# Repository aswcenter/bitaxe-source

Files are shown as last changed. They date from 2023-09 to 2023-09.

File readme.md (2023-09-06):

```
Closed Source is Antithetical to Bitcoin
```
# Presenting: The bitaxe
bitaxe is the first fully open source hardware Bitcoin ASIC miner.
bitaxeMax assembled

## Goals
- **Standalone**: can mine directly to your pool over WiFi. No External computer needed.
- **Embedded**: low cost, low maintenance, high availability, high reliability, low power.
- **ASIC**: based on the very efficient BM1397 from Bitmain.
- **Versatile**: solo/pool mining, autotune power/heat/efficiency.
- **Open Source**: All design files are provided.

## Features
- **ESP32-S3-WROOM-1** wifi microcontroller on board
- **TI TPS40305** buck regulator steps down the 5V input to power the BM1397
- **Maxim DS4432U+** current DAC digitally adjusts the BM1397 core voltage from 0.04V to 2.4V
- **TI INA260** power meter measures the input voltage and current of the miner
- **Microchip EMC2101** measures the BM1397 internal diode temperature. Also PWM controls the fan and monitors tach output.
- Two **sweet** RGB status LEDs
- 0.91" **SSD1306 OLED** I2C Display Module 

## BM1397
BM1397 pic

- The BM1397 is a undocumented SHA256 mining ASIC from Bitmain. It's mostly used in the Antminer S17 and T17
- Bitmain claims the BM1397 has 0.03J/GH efficiency
- The BM1397 is available (new) for around $20 each and (used) for around $6 ea in small quantities.
- Choose your BM1397 version: [Guide here](https://d-central.tech/bm1397-ad-ag-ah-ai-antminer-17-series-chip-replacement-guide/)
- The BM1397 has the same footprint as the BM1387, but a very different pinout.
    - It also has two "Modes" that change some of the signal pins around to make chaining easy
- The BM1397 is driven by an undocumented protocol over UART. Baudrate is 115200bps by default but can go up to 6Mbps in order to provide mining jobs quickly enough to the ASIC daisy-chain.

## Current Status
- v2.2 hardware has been built and tested -- it works!
- Using cgminer on a separate computer, the bitaxe can mine in excess of 400 GH/s
- ESP32 miner firmware is still underdevelopment.
    - Recently we have confirmed this is working! But it is not yet optimized. Check out [ESP-Miner](https://github.com/skot/esp-miner/tree/nonce_checking) for the latest. 
- This is an _advanced_ build! It's also still early days, so prolly not the best thing if you're just looking for a bitcoin miner to run.

## Hardware
- [BM1397 from random AliExpress seller](https://www.aliexpress.com/item/3256802274958527.html). I got the "AG" variant. Not really sure what the difference is.
- [40x40mm heatsink and 5V fan](https://www.aliexpress.com/item/2251832861666365.html) from a random AliExpress seller. At least half of these arrived broken in some way. But they are cheap and the working ones do keep the BM1387's nice and cool when used with some thermal compound.
    - Swap this fan with the [Noctua NF-A4x10](https://noctua.at/en/products/fan/nf-a4x10-pwm) 5V 4-Pin fan for a much more pleasant experience.
- The BM1397 serial port is 1.8V. These pins are broken out, but the main idea is to communicate with the BM1397 from the ESP32
- Level shifters to interface the 1.8V BM1397 with the 3.3V ESP32. These pins are also broken out.
- [KiCad 7](https://www.kicad.org) design files
- All of the parts on the board are listed in the KiCad BOM

## Software
- [ESP-Miner](https://github.com/skot/ESP-Miner) firmware in progress.
    - check out the `i2c_test` branch for a basic firmware to init all hardware (besides BM1397)
    - check out the `nonce_checking` branch for the latest developments in the ESP32 miner

### Testing
One of the best ways currently to test a new bitaxe is with a usbserial adapter and cgminer running on a separate computer.
- You need a basic firmware running on the ESP32 that will power up the ASIC. [ESP-Miner i2c_test](https://github.com/skot/esp-miner/tree/i2c_test) is good for this.
- You need a **1.8V** ftdi usbserial adapter. there are several on Amazon based on the FT232RL and one called "jim.sh" built on the FT230X
    - Connect the usbserial adapter to the 1.8V serial debug header on the bitaxe. It's the one below the heatsink next to the fan connector.
        - Make sure to connect the usbserial adapter `RTS` line to the bitaxe `RST` pin. Yes, that spelling is correct.
- Download and build the [cgminer-bitaxe](https://github.com/skot/cgminer-bitaxe) fork. 
    - This fork has a modified version of the GekkoScience CompacF driver to look for FT232RL or FT230X usbserial adapters and use the RTS signal for RST. 

## Power Supply Requirements
- [5VDC Power supply](https://www.amazon.com/BTF-LIGHTING-Plastic-Adapter-Transformer-WS2812B/dp/B01D8FM4N4). Should be capable of over 15W
    - Needs to connect with [spade-style connectors](https://www.amazon.com/gp/product/B01G4POUAU)

### ESP32 Programming Requirements
To program the onboard ESP32, you need the following tools;
- [ESP-Prog](https://www.digikey.com/en/products/detail/espressif-systems/ESP-PROG/10259352) ESP32 Programmer
- [TC2030-IDC-NL](https://www.tag-connect.com/product/tc2030-idc-nl) Tag Connect Cable
- [TC2030-CLIP](https://www.tag-connect.com/product/tc2030-retaining-clip-board-3-pack)
- This is best done with VSCode and the Espressif plugin

## Connections
bitaxeMax KiCad render

### Power Input
| Pin Name | Description |
| --- | --- |
| +5V | Main input. This should be 5V, 15W |
| GND | Main input ground |

## Building
- Check out [building.md](building.md) for PCB ordering tips
- Check out [assembly.md](assembly.md) for assembly tips

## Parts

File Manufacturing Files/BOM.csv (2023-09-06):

Id | Référence | Empreinte | Quantité | Désignation | Fournisseur et réf
1 | R26,R7,R27,R8 | R_0402_1005Metric | 4 | 100
2 | C43,C51 | C_0805_2012Metric | 2 | 10uF
3 | C19,C7,C1,C52,C33,C22,C42,C23,C29,C20,C9 | C_0402_1005Metric | 11 | 0.1uF
4 | U8 | TSSOP-16_4.4x5mm_P0.65mm | 1 | INA260
5 | D1 | SMA_L4.3-W2.6-LS5.2-RD | 1 | SS310
6 | R13 | R_0402_1005Metric | 1 | 1.33k
7 | C41 | C_0805_2012Metric | 1 | 1.5nF
8 | C3,C25,C50,C4,C12,C15,C16,C49,C18,C35,C10,C11,C14,C44,C6,C2,C5,C17,C8,C27,C24 | C_0402_1005Metric | 21 | 1uF
9 | C38 | C_0805_2012Metric | 1 | 1uF
10 | C45 | C_0805_2012Metric | 1 | 470pF
11 | Y1 | SC32S-7PF20PPM | 1 | 32.768kHz
12 | U5 | SOT-23-5 | 1 | MCP1824T-1802E
13 | R6,R36,R20,R4,R24,R9 | R_0402_1005Metric | 6 | 10k
14 | U6 | SOT-23-5 | 1 | MCP1824T-0802E
15 | U7 | TSSOP-8_3x3mm_P0.65mm | 1 | EMC2101
16 | R29,R28 | R_0402_1005Metric | 2 | 261
17 | C30,C31 | C_0402_1005Metric | 2 | 6.8pF
18 | , |  | 2
19 | U2 | TXB0104 | 1 | TXB0104RGYR
20 | R10 | R_0402_1005Metric | 1 | 3.83k
21 | L1 | FP1005R1-R15-R | 1 | 150nH
22 | R15 | R_0402_1005Metric | 1 | 3.32k
23 | R16 | R_0402_1005Metric | 1 | 80k
24 | C32 | C_0402_1005Metric | 1 | 470pF
25 | R3,R2,R5 | R_0402_1005Metric | 3 | 0
26 | C40 | C_0805_2012Metric | 1 | 180pF
27 | U10 | TSSOP-8_3x3mm_P0.65mm | 1 | DS4432U+
28 | C39 | C_0402_1005Metric | 1 | 3.3nF
29 | R14 | R_0402_1005Metric | 1 | 4.99k
30 | R11 | R_0402_1005Metric | 1 | 100k
31 | C13 | CP_EIA-7343-31_Kemet-D_Pad2.25x2.55mm_HandSolder | 1 | 330uF
32 | Q2,Q1 | CSD17311Q5 | 2 | CSD17311Q5
33 | U9 | TPS40305 | 1 | TPS40305
34 | C46 | CAP_2R5TPE220MAFB | 1 | 220uF
35 | R25 | R_0402_1005Metric | 1 | 19.1k
36 | R17 | R_0402_1005Metric | 1 | DNP
37 | C34,C36,C37 | C_1210_3225Metric | 3 | 47uF
38 | U1 | O 25,0-JO32-B-1V3-1-T1-LF | 1 | 25MHz
39 | R12 | R_0402_1005Metric | 1 | 4.12k
40 | R22,R21 | R_0402_1005Metric | 2 | 60,4
41 | C47 | C_1206_3216Metric | 1 | 100uF
42 | U11 | RT9080-33GJ5 | 1 | RT9080-33GJ5
43 | SW1,SW2 | SW_CS1213AGF260_CRS | 2 | GT-TC029B-H025-L1N
44 | J4 | 470531000 | 1 | Conn_01x04
45 | J2,J1 | 63862-1 | 2 | Conn_01x01
46 | J7 | PinHeader_1x02_P2.54mm_Vertical | 1 | Conn_01x02
47 | J3 | PinHeader_1x05_P2.54mm_Vertical | 1 | Conn_01x05
48 | U12 | ESP32-S3-WROOM-1 | 1 | ESP32-S3-WROOM-1
49 | IC1 | BM1397 | 1 | BM1397_mode1
50 | U13,U4 | CLX6E-FKC-CH1M1D1BB7C3D3 | 2 | CLX6E-FKC
51 | C28 | CP_Elec_6.3x7.7 | 1 | 220uF
52 | J11 | 2002112100006C1LF | 1 | 20021121-00006C1LF
53 | USB1 | USB_10118193-0001LF_AMP | 1 | 10118193-0001LF

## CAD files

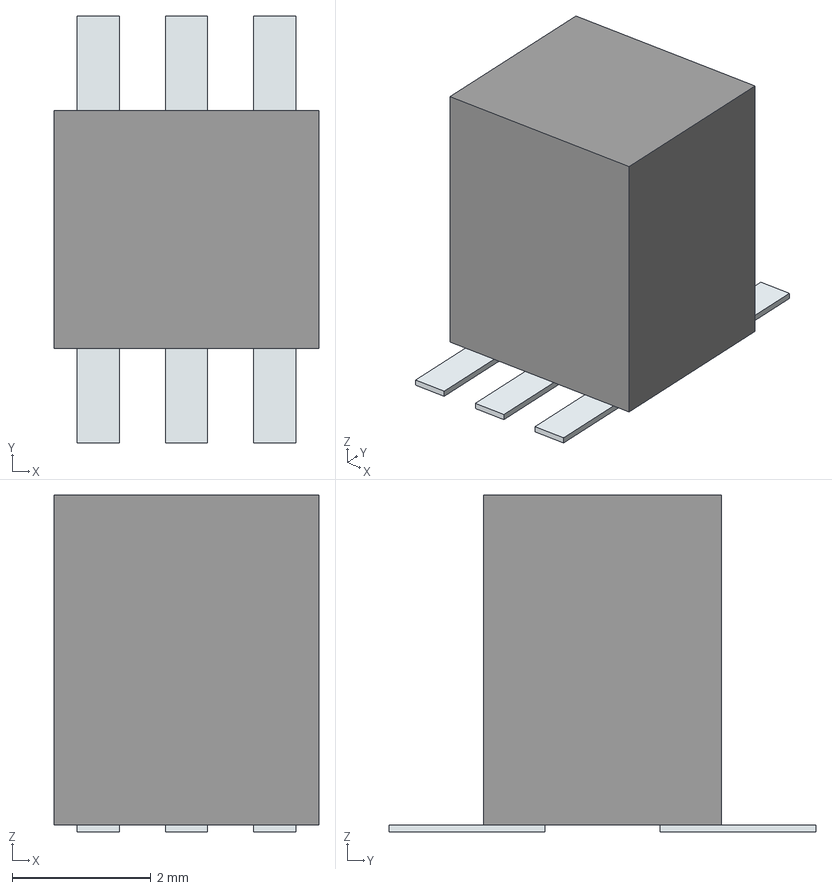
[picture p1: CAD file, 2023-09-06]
3d/20021121-00006C1LF.stp
3.81 x 6.15 x 4.85 mm
Pins

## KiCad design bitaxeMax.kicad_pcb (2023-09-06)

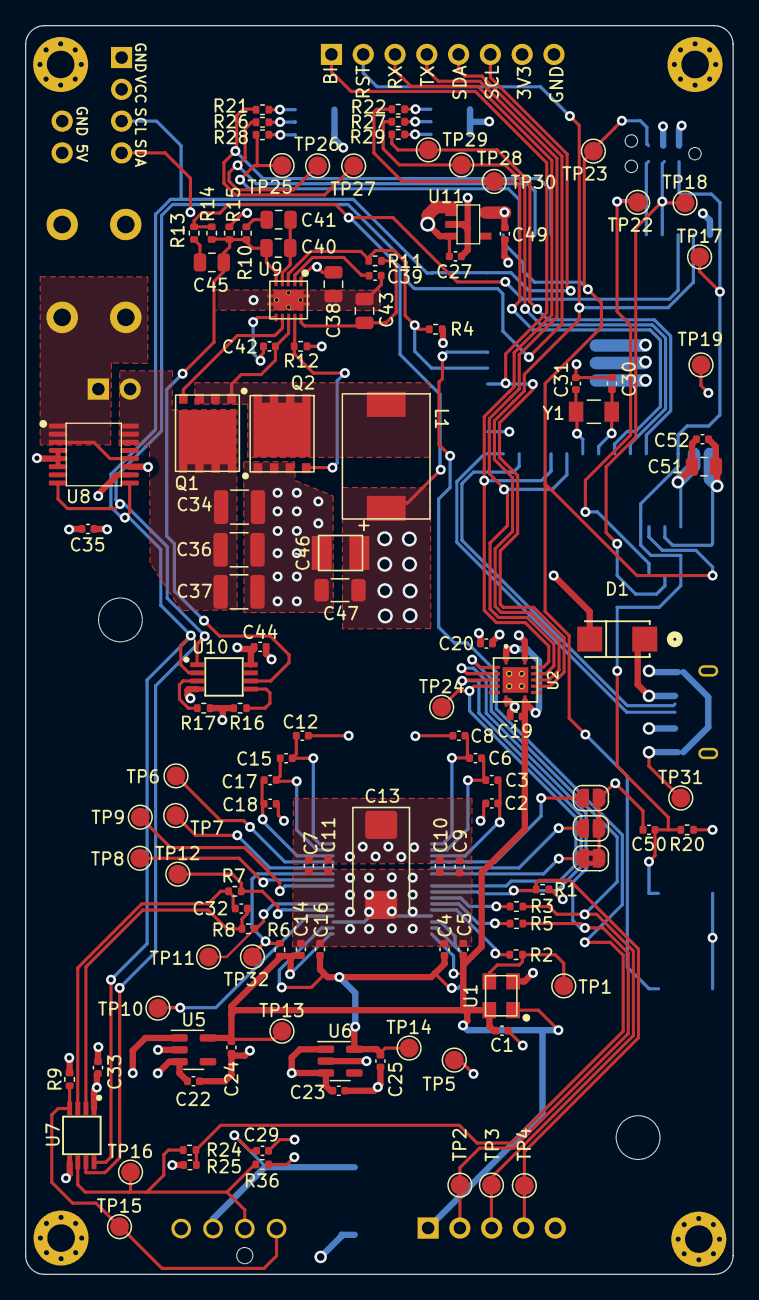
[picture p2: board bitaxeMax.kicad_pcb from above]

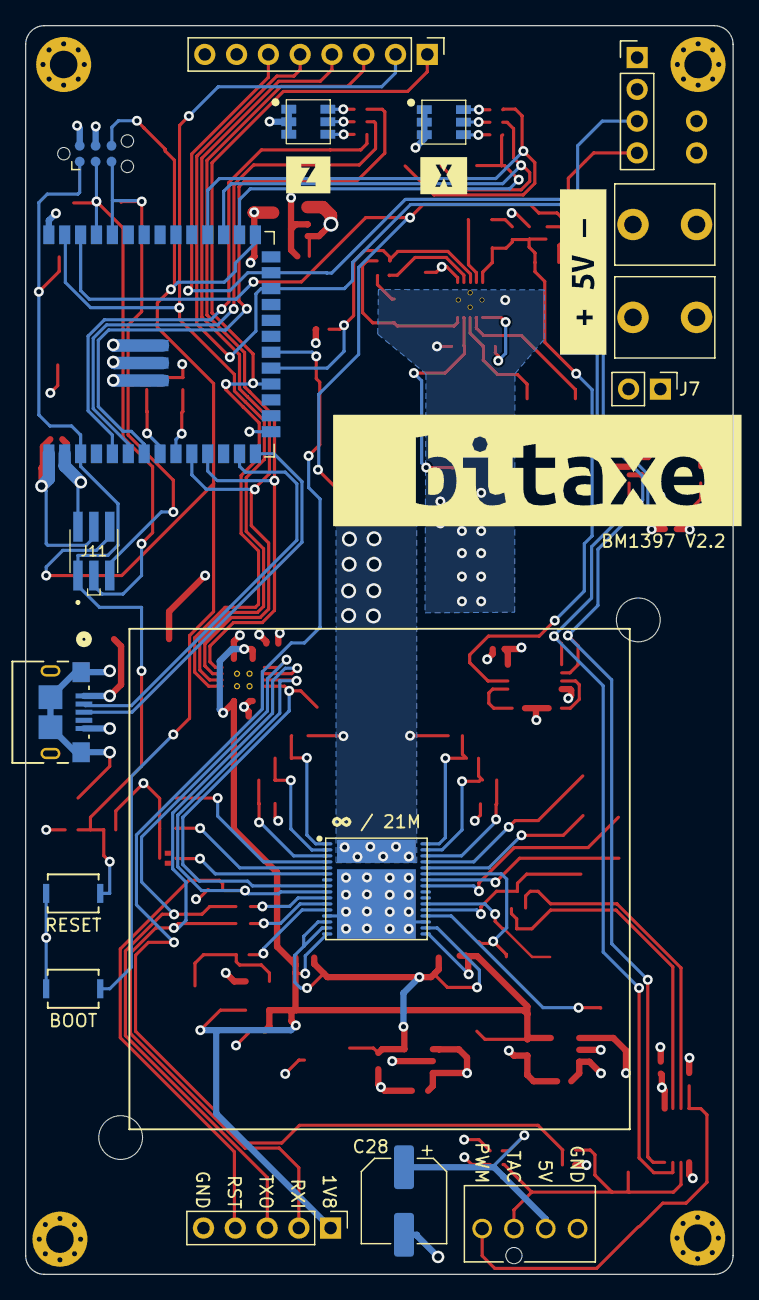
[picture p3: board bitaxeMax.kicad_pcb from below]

Board: 4 copper layers, 56.5 x 99.8 mm, 149 parts (21 on the bottom side), 77 nets.

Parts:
C1, C7, C9, C19, C20, C22, C23, C29, C33, C42, C52: 0.1uF; C_0402_1005Metric
C2, C3, C4, C5, C6, C8, C10, C11, C12, C14, C15, C16, C17, C18, C24, C25, C27, C35, C44, C49, C50: 1uF; C_0402_1005Metric
C13: 330uF; CP_EIA-7343-31_Kemet-D_Pad2.25x2.55mm_HandSolder
C28: 220uF; CP_Elec_6.3x7.7
C30, C31: 6.8pF; C_0402_1005Metric
C32: 470pF; C_0402_1005Metric
C34, C36, C37: 47uF; C_1210_3225Metric
C38: 1uF; C_0805_2012Metric
C39: 3.3nF; C_0402_1005Metric
C40: 180pF; C_0805_2012Metric
C41: 1.5nF; C_0805_2012Metric
C43, C51: 10uF; C_0805_2012Metric
C45: 470pF; C_0805_2012Metric
C46: 220uF; CAP_2R5TPE220MAFB
C47: 100uF; C_1206_3216Metric
D1: SS310; SMA_L4.3-W2.6-LS5.2-RD
H1, H2, H3, H4: AlignmentHole; MountingHole_2.2mm_M2_Pad_Via
H5, H6: MountingHole; MountingHole_3.5mm
IC1: BM1397_mode1; BM1397
J1, J2: Conn_01x01; 63862-1
J3: Conn_01x05; PinHeader_1x05_P2.54mm_Vertical
J4: Conn_01x04; 470531000
J5: TC2030-IDC; Tag-Connect_TC2030-IDC-NL_2x03_P1.27mm_Vertical
J6: Conn_01x08; PinHeader_1x08_P2.54mm_Vertical
J7: Conn_01x02; PinHeader_1x02_P2.54mm_Vertical
J9: Conn_01x04; PinHeader_1x04_P2.54mm_Vertical
J11: 20021121-00006C1LF; 2002112100006C1LF
JP1, JP2: SolderJumper_2_Open; SolderJumper-2_P1.3mm_Open_RoundedPad1.0x1.5mm
JP3: SolderJumper_2_Bridged; SolderJumper-2_P1.3mm_Bridged2Bar_RoundedPad1.0x1.5mm
L1: 150nH; FP1005R1-R15-R
Q1, Q2: CSD17311Q5
R1: 1k; R_0402_1005Metric
R2, R3, R5: 0; R_0402_1005Metric
R4, R6, R9, R20, R24, R36: 10k; R_0402_1005Metric
R7, R8, R26, R27: 100; R_0402_1005Metric
R10: 3.83k; R_0402_1005Metric
R11: 100k; R_0402_1005Metric
R12: 4.12k; R_0402_1005Metric
R13: 1.33k; R_0402_1005Metric
R14: 4.99k; R_0402_1005Metric
R15: 3.32k; R_0402_1005Metric
R16: 80k; R_0402_1005Metric
R17: DNP; R_0402_1005Metric
R21, R22: 60.4; R_0402_1005Metric
R25: 19.1k; R_0402_1005Metric
R28, R29: 261; R_0402_1005Metric
SW1, SW2: GT-TC029B-H025-L1N; SW_CS1213AGF260_CRS
TP1, TP2, TP3, TP4, TP5, TP6, TP7, TP8, TP9, TP10, TP11, TP12, TP13, TP14, TP15, TP16, TP17, TP18, TP19, TP22, TP23, TP24, TP25, TP26, TP27, TP28, TP29, TP30, TP31, TP32: TestPoint; TestPoint_Pad_D1.5mm
U1: 25MHz; O 25,0-JO32-B-1V3-1-T1-LF
U2: TXB0104RGYR; TXB0104
U4, U13: CLX6E-FKC; CLX6E-FKC-CH1M1D1BB7C3D3
U5: MCP1824T-1802E; SOT-23-5
U6: MCP1824T-0802E; SOT-23-5
U7: EMC2101; TSSOP-8_3x3mm_P0.65mm
U8: INA260; TSSOP-16_4.4x5mm_P0.65mm
U9: TPS40305
U10: DS4432U+; TSSOP-8_3x3mm_P0.65mm
U11: RT9080-33GJ5
U12: ESP32-S3-WROOM-1
USB1: 10118193-0001LF; USB_10118193-0001LF_AMP
Y1: 32.768kHz; SC32S-7PF20PPM
kibuzzard-63D74789: G***; kibuzzard-63D74789
kibuzzard-6387EEBE: G***; kibuzzard-6387EEBE
kibuzzard-6387EECB: G***; kibuzzard-6387EECB
kibuzzard-6392B1E5: G***; kibuzzard-6392B1E5

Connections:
/3V3: C20.1, C33.1, C35.1, C44.1, C49.1, C51.1, C52.1, J5.2, J6.7, J9.2, J11.2, R4.1, R9.2, R20.1, R36.2, TP19.1, U2.14 (VCCB), U7.1 (VDD), U8.10 (VS), U10.8 (VCC), U11.5 (VOUT), U12.2 (3V3), U12.15 (GPIO3/TOUCH3/ADC1_CH2*)
/5V: C22.1, C23.1, C27.1, C28.1, C29.1, C34.1, C36.1, C37.1, C38.1, D1.1, J4.2, J7.2, Q1.5 (D), U5.1 (VIN), U5.3 (EN), U6.1 (VIN), U6.3 (EN), U8.14 (IN-), U8.15 (IN-), U8.16 (IN-), U9.1 (VDD), U11.1 (VIN), U11.3 (EN)
/BI: J6.1, U2.10 (B4), U12.18 (GPIO10/TOUCH10/ADC1_CH9/FSPICS0/FSPIIO4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)
/BM1397/0V8: C4.1, C16.1, C25.1, IC1.14 (PLL_VDD), IC1.15 (VDDIO_08_0), IC1.18 (VDDIO_08_1), TP14.1, U6.5 (VOUT)
/BM1397/1V8: C1.2, C5.1, C14.1, C19.1, C24.1, IC1.16 (VDDIO_18_0), IC1.17 (VDDIO_18_1), J3.1, R6.2, TP13.1, U1.1 (EN), U1.4 (VIN), U2.1 (VCCA), U2.8 (OE), U5.5 (VOUT)
/BM1397/BM_BI: IC1.8 (BI), TP24.1, U2.5 (A4)
/BM1397/BM_CLKI: IC1.12 (CLKI), R2.2
/BM1397/CI: J3.2, R5.1, TP2.1, U2.3 (A2)
/BM1397/RO: J3.3, R3.1, TP3.1, U2.2 (A1)
/BM1397/RST_N: IC1.9 (NRSTI), J3.4, R1.2, TP4.1, U2.4 (A3)
/ESP32/EN: C50.1, J5.1, J11.1, R20.2, SW1.2, TP17.1, U12.3 (EN)
/ESP32/FAN_ALERT: R24.1, R25.2, U12.20 (GPIO12/TOUCH12/ADC2_CH1/FSPICLK/FSPIIO6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)
/ESP32/IO0: J5.6, J11.6, SW2.2, TP23.1, U12.27 (GPIO0/BOOT*)
/ESP32/LEDX_B: R21.1, TP27.1, U12.30 (SPIDQS/GPIO37/FSPIQ/SUBSPIQ)
/ESP32/LEDX_G: R26.1, TP26.1, U12.29 (SPIIO7/GPIO36/FSPICLK/SUBSPICLK)
/ESP32/LEDX_R: R28.1, TP25.1, U12.28 (SPIIO6/GPIO35/FSPID/SUBSPID)
/ESP32/LEDZ_B: R22.1, TP30.1, U12.7 (GPIO7/TOUCH7/ADC1_CH6)
/ESP32/LEDZ_G: R27.1, TP29.1, U12.6 (GPIO6/TOUCH6/ADC1_CH5)
/ESP32/LEDZ_R: R29.1, TP28.1, U12.5 (GPIO5/TOUCH5/ADC1_CH4)
/ESP32/P_RX: J5.5, J11.5, TP22.1, U12.36 (U0RXD/GPIO44/CLK_OUT2)
/ESP32/P_TX: J5.3, J11.3, TP18.1, U12.37 (U0TXD/GPIO43/CLK_OUT1)
/ESP32/XIN32: C30.1, U12.8 (GPIO15/U0RTS/ADC2_CH4/XTAL_32K_P), Y1.1
/ESP32/XOUT32: C31.1, U12.9 (GPIO16/U0CTS/ADC2_CH5/XTAL_32K_NH5), Y1.2
/Fan/FAN_PWM: J4.4, R9.1, TP15.1, U7.4 (FAN)
/Fan/FAN_TACH: J4.3, R24.2, R36.1, TP16.1, U7.6 (ALERT/TACH)
/Power/OUT0: C40.2, C45.2, R10.2, R14.2, R15.1, U9.5 (FB), U10.6 (OUT0)
/Power/PGOOD: R4.2, R11.1, U9.3 (PGOOD), U12.19 (GPIO11/TOUCH11/ADC2_CH0/FSPID/FSPIIO5/S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)
/Power/SW: C42.2, L1.1, Q1.1, Q1.2, Q1.3 (S), Q2.5 (D), U9.8 (SW)
/Power/VIN: J1.1, J7.1, U8.1 (IN+), U8.2 (IN+), U8.3 (IN+), U8.12 (VBUS)
/RST: J6.2, U2.11 (B3), U12.39 (GPIO1/TOUCH1/ADC1_CH0)
/RX: J6.3, U2.13 (B1), U12.11 (GPIO18/U1RXD/ADC2_CH7/CLK_OUT3)
/SCL: J6.6, J9.3, U7.8 (SMCLK), U8.9 (SCL), U10.2 (SCL), U12.25 (GPIO48/SPICLK_N/SUBSPICLK_N_DIFF)
/SDA: J6.5, J9.4, U7.7 (SMDATA), U8.8 (SDA), U10.1 (SDA), U12.24 (GPIO47/SPICLK_P/SUBSPICLK_P_DIFF)
/TEMP_N: IC1.21 (TEMP_N), R7.2, TP12.1
/TEMP_P: IC1.22 (TEMP_P), R8.1, TP11.1
/TX: J6.4, U2.12 (B2), U12.10 (GPIO17/U1TXD/ADC2_CH6)
/VDD: C7.1, C8.2, C9.1, C10.1, C11.1, C12.1, C13.1, C46.1, C47.1, IC1.33 (VDD), L1.2, R13.1, R14.1, U12.38 (GPIO2/TOUCH2/ADC1_CH1)
GND: C1.1, C2.1, C4.2, C5.2, C7.2, C9.2, C10.2, C11.2, C13.2, C14.2, C16.2, C18.2, C19.2, C20.2, C22.2, C23.2, C24.2, C25.2, C27.2, C28.2, C29.2, C30.2, C31.2, C33.2, C34.2, C35.2, C36.2, C37.2, C38.2, C39.2, C43.2, C44.2, C46.2, C47.2, C49.2, C50.2, C51.2, C52.2, IC1.13 (PLL_VSS), IC1.19 (VSS), IC1.34 (VSS_0), J2.1, J3.5, J4.1, J5.4, J6.8, J9.1, J11.4, JP1.1 (A), JP2.1 (A), JP3.1 (A), Q2.1, Q2.2, Q2.3 (S), R1.1, R12.2, R15.2, R16.2, R17.2, R25.1, SW1.1, SW2.1, TP5.1, TP31.1, U1.2 (GND), U2.7 (GND), U2.15 (GND), U2.16 (GND), U2.17 (GND), U2.18 (GND), U2.19 (GND), U4.1 (BC), U4.2 (GC), U4.3 (RC), U5.2 (GND), U6.2 (GND), U7.5 (GND), U8.4 (A1), U8.5 (A0), U8.6 (GND), U8.11 (GND), U9.11 (GND), U10.4 (GND), U11.2 (GND), U12.1 (GND), U12.40 (GND), U12.41 (GND), U13.1 (BC), U13.2 (GC), U13.3 (RC), USB1.5 (GND), USB1.6, USB1.7, USB1.8, USB1.9
unnamed: C41.2, R10.1
unnamed: C45.1, R13.2
unnamed: IC1.4 (ADDR0), JP1.2 (B)
unnamed: IC1.5 (ADDR1), JP2.2 (B)
unnamed: IC1.6 (ADDR2), JP3.2 (B)
unnamed: IC1.29 (BO), TP6.1
unnamed: IC1.11 (CI), R5.2
unnamed: IC1.25 (CLKO), TP9.1
unnamed: IC1.26 (CO), TP8.1
unnamed: IC1.28 (NRSTO), TP7.1
unnamed: IC1.20 (PIN_MODE), TP10.1
unnamed: IC1.27 (RI), R6.1, TP32.1
unnamed: IC1.10 (RO), R3.2
unnamed: C2.2, C3.1, IC1.3 (VDD1_0)
unnamed: C17.2, C18.1, IC1.30 (VDD1_1)
unnamed: C3.2, C6.1, IC1.2 (VDD2_0)
unnamed: C15.2, C17.1, IC1.31 (VDD2_1)
unnamed: C6.2, C8.1, IC1.1 (VDD3_0)
unnamed: C12.2, C15.1, IC1.32 (VDD3_1)
unnamed: Q1.4 (G), U9.7 (HDRV)
unnamed: Q2.4 (G), R12.1, U9.9 (LDRV)
unnamed: R2.1, TP1.1, U1.3 (OUT)
unnamed: R21.2, U4.6 (BA)
unnamed: R26.2, U4.5 (GA)
unnamed: R28.2, U4.4 (RA)
unnamed: C32.2, R7.1, U7.3 (DN)
unnamed: C32.1, R8.2, U7.2 (DP)
unnamed: C42.1, U9.6 (BOOT)
unnamed: C43.1, R11.2, U9.10 (BP)
unnamed: C40.1, C41.1, U9.4 (COMP)
unnamed: C39.1, U9.2 (SS)
unnamed: R16.1, U10.5 (FS0)
unnamed: R17.1, U10.3 (FS1)
unnamed: U12.13 (GPIO19/U1RTS/ADC2_CH8/CLK_OUT2/USB_D-), USB1.2 (D-)
unnamed: U12.14 (GPIO20/U1CTS/ADC2_CH9/CLK_OUT1/USB_D+), USB1.3 (D+)
unnamed: R22.2, U13.6 (BA)
unnamed: R27.2, U13.5 (GA)
unnamed: R29.2, U13.4 (RA)
unnamed: D1.2, USB1.1 (VBUS)
